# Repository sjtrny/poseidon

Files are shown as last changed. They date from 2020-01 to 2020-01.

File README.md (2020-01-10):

# poseidon

Poseidon is a custom built humidifier. This repository contains:
- parts list
- wiring diagram
- required software and setup instructions

## Overview

Poseidon uses two relays to control power to:
- a fan
- a fogger (ultrasonic mist maker)

There is optional PWM control of the fan speed if using a 4-wire PWM fan.

Poseidon runs on [ESPHome](https://esphome.io). See `poseidon.yml`  for the configuration of the device.

## Parts List

The parts list can be found in the `parts.xlsx` file.

## Hardware and Wiring

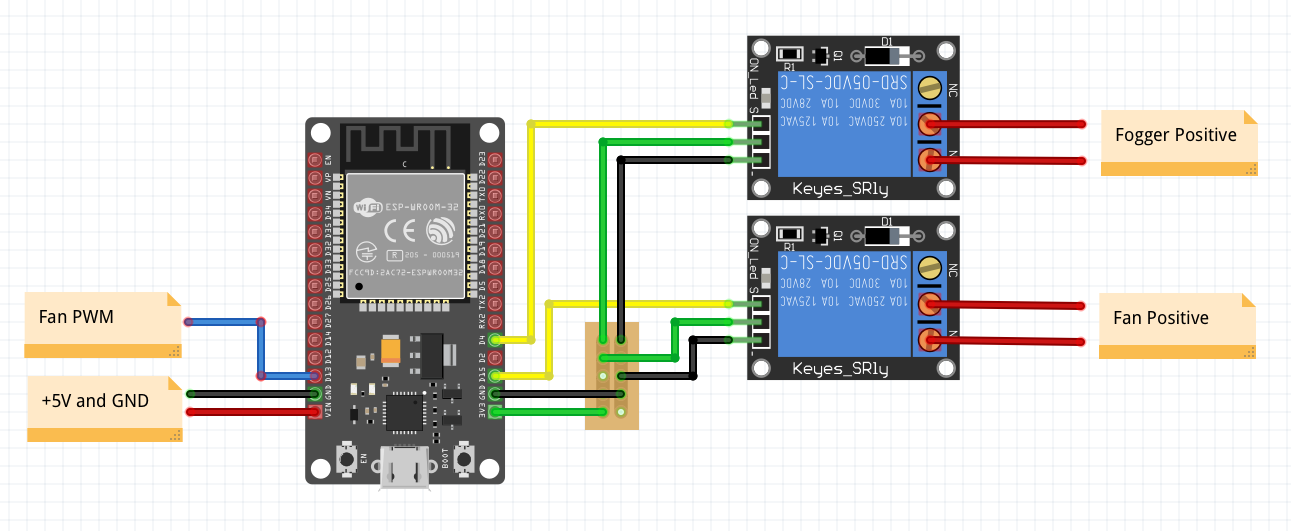
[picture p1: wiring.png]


## Instructions

1. Create virtual environment and install dependencies

```
./setup.sh
```

2. Activate virtual environment

```
source venv/bin/activate
```

3. Add wifi details to  `gaia.yml`

4. Plug in ESP32 via USB

5. Compile and upload to ESP32

```
esphome poseidon.yml run
```

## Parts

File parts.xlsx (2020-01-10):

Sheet: Parts
Unit Price | Count | Total | Name | Link
$17.99 | 1 | $17.99 | 3/4" to 1/4" Adapter | https://www.ebay.com.au/itm/3-4-BSP-FI-x-1-4-Female-Adaptor-Fridge-Water-Filter-Connector-John-Guest-Tube/162551449970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
$9.29 | 1 | $9.29 | Float Valve 1/4" | https://www.ebay.com.au/itm/1-4-Float-Valve-Ball-Cock-Adjustable-Aquarium-Fish-Water-Tank-Pond-Auto-Filler/202797720944
$12.30 | 1 | $12.30 | 1/4" Tubing 3m | https://www.bunnings.com.au/aquaport-1-4-x-3m-tubing_p5090122
$120 | 1 | $120.00 | 12 Head Ultrasonic Fogger and Power Supply | https://www.ebay.com.au/itm/250W-10-Head-Ultrasonic-Mist-Maker-Industry-Fogger-Humidifier-250W-Power/173834963396
$55 | 1 | $55.00 | Fan - Noctua NF-12 IP67 3000RPM | https://www.umart.com.au/Noctua-NF-12-120mm-Industrial-PPC-3000RPM-Q100-IP67-3000RPM-PWM-Fan_50910G.html
$20.99 | 1 | $20.99 | IP65 Junction Box (255 x 200 x 120mm) | https://www.ebay.com.au/itm/Large-ABS-IP65-Waterproof-Junction-Box-Case-Universal-Electrical-Enclosure-Cable/113385445669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
$10.98 | 2 | $21.96 | DC-DC Step Down | https://www.ebay.com.au/itm/DC-DC-Buck-Converter-Voltage-Regulator-Step-Down-Module-10A-24V-60V-to-3V-19V-AU/183966541868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
$14.99 | 1 | $14.99 | ESP32 | https://www.ebay.com.au/itm/AU-ESP-WROOM-32-ESP32-ESP32S-2-4GHz-WiFi-Bluetooth-Development-Board-for-Arduino/303428770355
$3.99 | 2 | $7.98 | 5V Single Channel Relay Module 10A | https://core-electronics.com.au/5v-single-channel-relay-module-10a.html
$6.20 | 1 | $6.20 | Terminal Strip | https://www.bunnings.com.au/hpm-6-terminal-strip-connector_p4330504
$8.95 | 1 | $8.95 | 4-Way Deutsch Connector | https://www.jaycar.com.au/4-way-weatherproof-deutsch-connector-set/p/PP2149
$6.95 | 1 | $6.95 | 2-Way Deutsch Connector | https://www.jaycar.com.au/waterproof-deutsch-2-way-connector-set/p/PP2150
$5.95 | 1 | $5.95 | Mains Plug to Bare Wires 1.8m | https://www.jaycar.com.au/3pin-mains-plug-to-bare-wires-1-8m/p/PS4110
$3.90 | 2 | $7.80 | 4 Core Speaker Cable (per metre) | https://www.jaycar.com.au/pro-audio-speaker-cable-4-core-sold-per-metre/p/WB1762
$2.50 | 2 | $5.00 | 2 Core Cable (per metre) | https://www.jaycar.com.au/15a-twin-core-power-cable-sold-per-metre/p/WH3079
$4.81 | 2 | $9.62 | 18AWG Silicone Wire (Red and Black) | https://core-electronics.com.au/high-temperature-resistant-silicone-wire-18awg-0-75mm2-1m-red-black.html
$16.99 | 1 | $16.99 | Handy 30L Black Storage Box | https://www.bunnings.com.au/handy-storage-30l-black-heavy-duty-crate_p0056608
$9.80 | 1 | $9.80 | Handy Storage Lid | https://www.bunnings.com.au/handy-storage-30l-54l-70l-black-storage-crate-lid_p2580618
$3.35 | 1 | $3.35 | M4 x 35mm Screws | https://www.bunnings.com.au/pinnacle-m4-x-35mm-zinc-plated-thread-screw-10-pack_p2251390
$6.50 | 1 | $6.50 | M4 Rivnuts | https://www.bunnings.com.au/kincrome-m4-20-piece-rivnut-set_p5910348
$1.20 | 1 | $1.20 | Cable Ties | https://www.bunnings.com.au/electrical-cable-ties_p4431081
$4.06 | 1 | $4.06 | Narva 19mm Cable Tie Mounts | https://www.bunnings.com.au/narva-19mm-black-cable-tie-mounts-5-pack_p4430668
$5.95 | 1 | $5.95 | Socket to Socket Jumper Leads | https://www.jaycar.com.au/150mm-socket-to-socket-jumper-leads-40-piece/p/WC6026
$6.95 | 1 | $6.95 | IC Experimenters Board | https://www.jaycar.com.au/ic-experimenters-board-140-x-95mm/p/HP9558
$0.95 | 1 | $0.95 | Male Header Strip | https://www.jaycar.com.au/40-pin-header-terminal-strip/p/HM3212
$1.80 | 1 | $1.80 | Female Header Strip | https://www.jaycar.com.au/40-pin-female-header-strip/p/HM3230
$5.95 | 1 | $5.95 | Socker to Socker Leads | https://www.jaycar.com.au/150mm-socket-to-socket-jumper-leads-40-piece/p/WC6026
 |  | $394.47
 |  | Consumables are not included e.g. heatshrink or solder
 |  | Shipping included if eBay item, otherwise not included

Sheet: Tools
Price | Name | Link
$29.99 | Rivet Nut Tool | https://www.supercheapauto.com.au/p/toolpro-toolpro-rivet-nut-tool/523129.html
$19.98 | Holesaw Set | https://www.bunnings.com.au/hole-saw-drill-bit-kits-sc_p6372275?gclsrc=aw.ds
 | Multimeter
 | Drill + Step Drill Set/Drill bits | https://www.bunnings.com.au/craftright-3-piece-step-drill-set_p0027584
 | Heat Gun (for heatshrink but you can use a BBQ or regular lighter)
 | Screw Drivers (Small and Normal Sizes)
 | Side Cutters
 | Pliers
 | Tweezers
 | Stanley Knife

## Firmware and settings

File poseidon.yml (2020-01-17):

esphome:
  name: poseidon
  platform: ESP32
  board: esp32doit-devkit-v1

# Enable logging
#logger:
#  level: VERY_VERBOSE

status_led:
  pin:
    number: GPIO2

wifi:
  ssid: "SSID"
  password: "PASSWORD"

  # Enable fallback hotspot (captive portal) in case wifi connection fails
  ap:
    ssid: "poseidon Fallback Hotspot"
    password: "wGmReCrulAVP"

web_server:
  port: 80

# Enable Home Assistant API
api:
  reboot_timeout: 2min

ota:

time:
  - platform: homeassistant
    id: homeassistant_time

binary_sensor:
  - platform: status
    name: "Poseidon Status"

output:
  - platform: ledc
    pin: 13
    id: gpio_13
    frequency: 25000
    min_power: 0.5
    max_power: 1.0

light:
  - platform: monochromatic
    output: gpio_13
    name: "Poseidon Fan Speed"

switch:
  - platform: gpio
    name: "Poseidon Fan"
    pin: 15
    id: poseidon_fan
    restore_mode: ALWAYS_OFF
  - platform: gpio
    name: "Poseidon Fogger"
    pin: 4
    id: poseidon_fogger
    restore_mode: ALWAYS_OFF
  - platform: template
    name: "Poseidon"
    lambda: |-
      if (id(poseidon_fan).state || id(poseidon_fogger).state ) {
        return true;
      } else {
        return false;
      }
    turn_on_action:
      - switch.turn_on: poseidon_fan
      - switch.turn_on: poseidon_fogger
    turn_off_action:
      - switch.turn_off: poseidon_fan
      - switch.turn_off: poseidon_fogger

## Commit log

2020-01-05 Added content
    [parts.xlsx, wiring.fzz]
2020-01-05 Updated wiring image
2020-01-06 Updated parts list and improved instructions
    [parts.xlsx]
2020-01-10 Migrated to ESPHome
    [parts.xlsx, wiring.fzz]
2020-01-17 Added failsafe (2 min) on loss connection to HA
    [poseidon.yml]
